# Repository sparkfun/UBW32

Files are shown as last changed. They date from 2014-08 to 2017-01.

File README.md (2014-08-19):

USB 32-Bit Whacker-PIC32MX795 Development Board
================================================

[UBW32
*USB 32-Bit Whacker (DEV-09713)*](https://www.sparkfun.com/products/9713)

This breadboard friendly development board enables you to get the PIC32 up and running quickly. 
Power can be provided over USB, there are 3 push buttons (including 2 user-defined buttons),
and 5 indicator LEDs. The board comes pre-loaded with a USB bootloader and special UBW firmware that accepts
simple serial commands to control the various I/O functions. 

Repository Contents
-------------------
* **/Hardware** - All Eagle design files (.brd, .sch, .STL)

License Information
-------------------
Distributed as-is; no warranty is given.

This product is a collaboration with Brian Schmalz.

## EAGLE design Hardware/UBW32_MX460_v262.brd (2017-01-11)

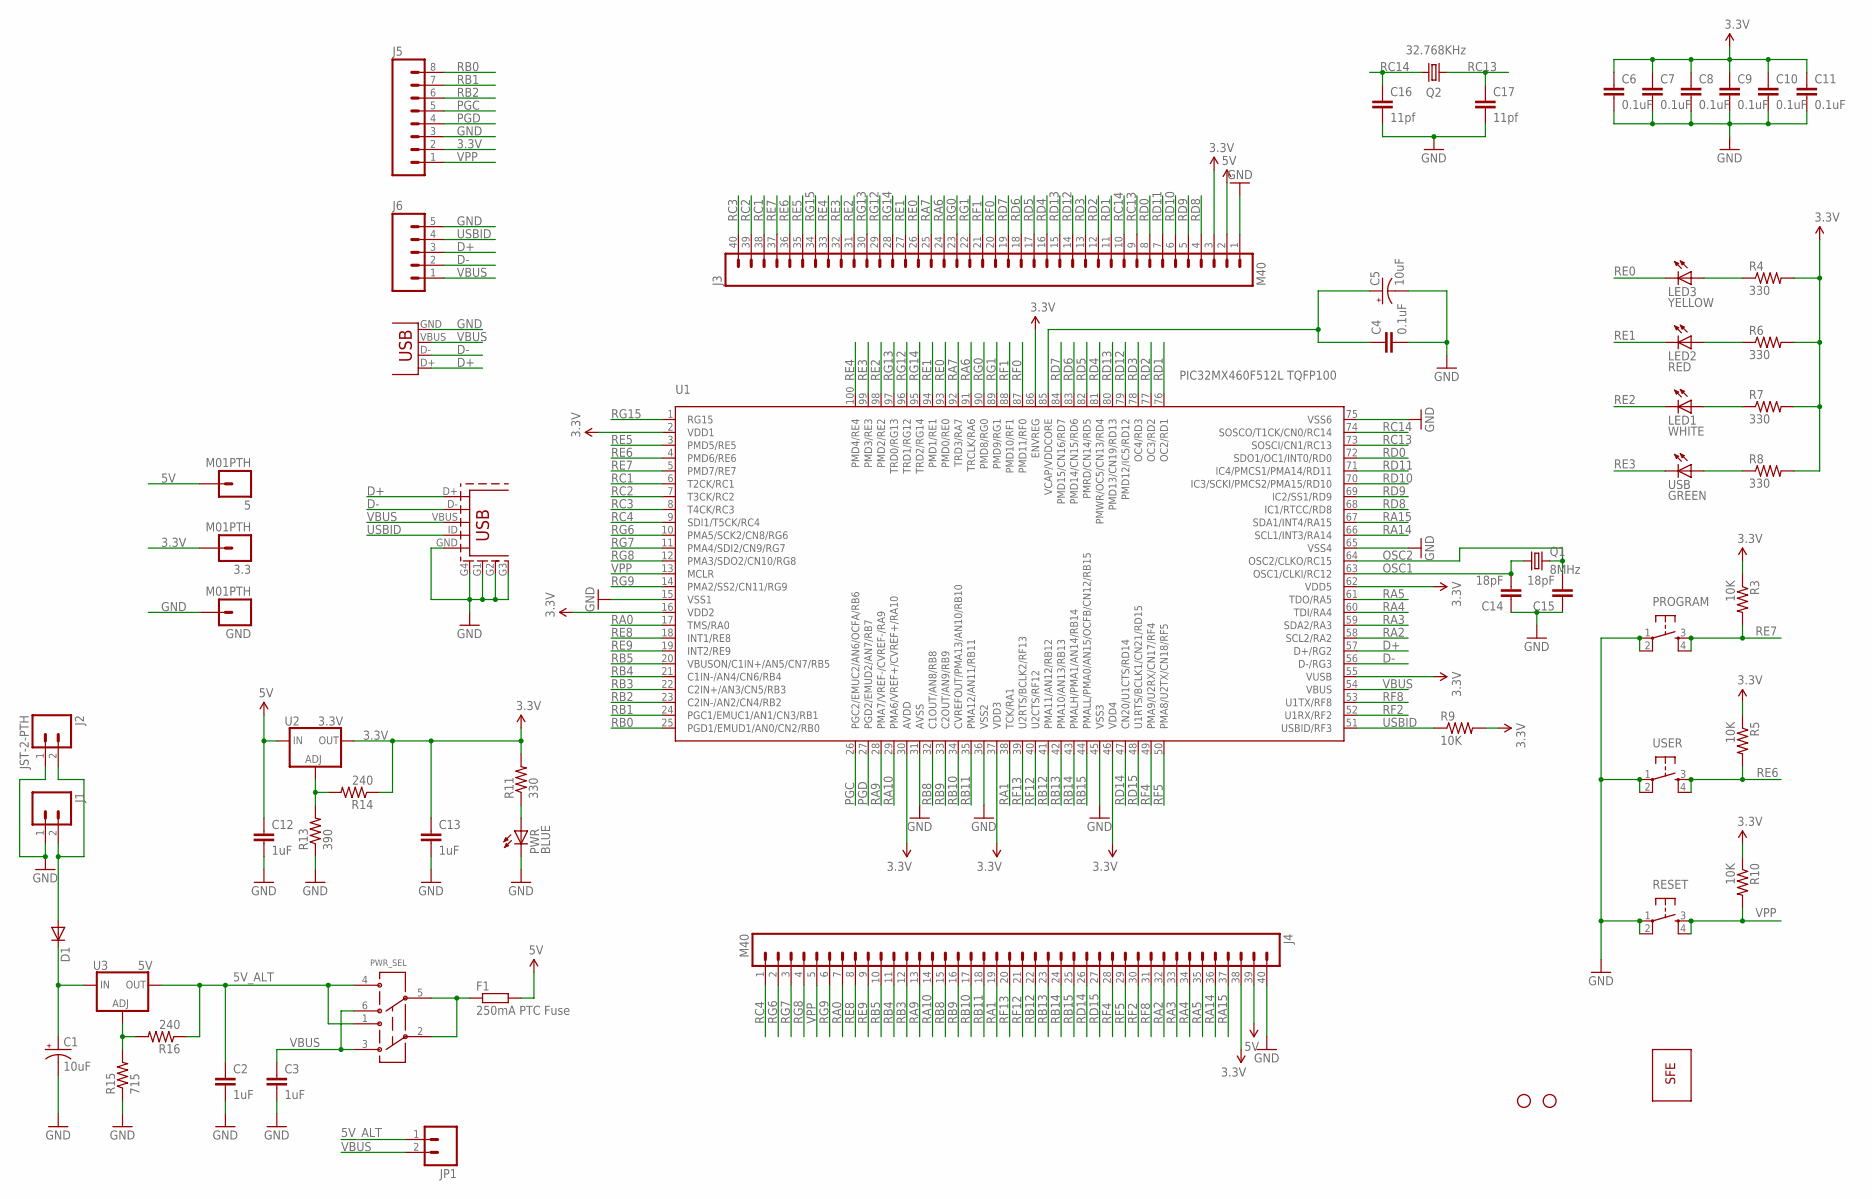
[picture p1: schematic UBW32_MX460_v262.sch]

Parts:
3.3, 5: M01PTH; 1X01
C1, C5: 10uF; EIA3528
C2, C3: 1uF; 0402-CAP
C4, C6, C7, C8, C9, C11: 0.1uF; 0402-CAP
C10: 0.1uF; C0402
C12, C13: 1uF; C0402
C14, C15: 18pF; 0402-CAP
C16, C17: 11pf; 0402-CAP
D1: DIODESMA; SMA-DIODE
F1: 250mA PTC Fuse; R1206
GND: M01PTH; 1X01
J1: M02PTH; 1X02
J2: JST-2-PTH; S2B-PH
J3, J4: M40; 1X40
J5: M08; 1X08
J6: M05PTH; 1X05
J7: USB-A-S
J8: USB-MINIB
JP1: M02PTH; 1X02
LED1: WHITE; LED-0603
LED2: RED; LED-0603
LED3: YELLOW; LED-0603
PROGRAM: TAC_SWITCHSND; TACTILE_SWITCH_SMD
PWR: BLUE; LED-0603
PWR_SEL: AYZ0202
Q1: 8MHz; CRYSTAL-SMD-5X3
Q2: 32.768KHz; CRYSTAL-32KHZ-SMD
R3, R5, R9, R10: 10K; 0402-RES
R4, R6, R7, R8, R11: 330; 0402-RES
R13: 390; 0402-RES
R14, R16: 240; 0402-RES
R15: 715; 0402-RES
RESET: TAC_SWITCHSND; TACTILE_SWITCH_SMD
U1: PIC32MX460F512L TQFP100; TQFP100
U2: 3.3V; SOT223
U3: 5V; SOT223
U$4: LOGO-SFENEW; SFE-NEW-WEBLOGO
U$6, U$7: STAND-OFF
USB: GREEN; LED-0603
USER: TAC_SWITCHSND; TACTILE_SWITCH_SMD

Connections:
3.3V: 3.3.1, C6.1, C7.1, C8.1, C9.1, C10.1, C11.1, C13.1, J3.3, J4.38, J5.2, R3.1, R4.2, R5.1, R6.2, R7.2, R8.2, R9.2, R10.1, R11.2, R14.1, U1.2 (VDD1), U1.16 (VDD2), U1.30 (AVDD), U1.37 (VDD3), U1.46 (VDD4), U1.55 (VUSB), U1.62 (VDD5), U1.86 (ENVREG), U2.2 (OUT)
5V: 5.1, C12.1, F1.2, J3.2, J4.39, U2.3 (IN)
5V_ALT: C2.1, JP1.1, PWR_SEL.1 (3), PWR_SEL.4 (6), R16.1, U3.2 (OUT)
D+: J6.3, J7.D+, J8.D+, U1.57 (D+/RG2)
D-: J6.2, J7.D-, J8.D-, U1.56 (D-/RG3)
GND: C1.C (-), C2.2, C3.2, C4.2, C5.C (-), C6.2, C7.2, C8.2, C9.2, C10.2, C11.2, C12.2, C13.2, C14.1, C15.1, C16.2, C17.2, GND.1, J1.1, J2.1, J3.1, J4.40, J5.3, J6.5, J7.GND, J8.G1, J8.G2, J8.G3, J8.G4 (SHIELD), J8.GND, PROGRAM.1, PROGRAM.2, PWR.C, R13.1, R15.1, RESET.1, RESET.2, U1.15 (VSS1), U1.31 (AVSS), U1.36 (VSS2), U1.45 (VSS3), U1.65 (VSS4), U1.75 (VSS6), USER.1, USER.2
unnamed: D1.A, J1.2, J2.2
unnamed: F1.1, PWR_SEL.2, PWR_SEL.5
unnamed: R13.2, R14.2, U2.1 (ADJ)
unnamed: R15.2, R16.2, U3.1 (ADJ)
unnamed: PWR.A, R11.1
unnamed: R8.1, USB.A
unnamed: LED1.A, R7.1
unnamed: LED2.A, R6.1
unnamed: LED3.A, R4.1
unnamed: C4.1, C5.A (+), U1.85 (VCAP/VDDCORE)
OSC1: C14.2, Q1.1, U1.63 (OSC1/CLKI/RC12)
OSC2: C15.2, Q1.3 (2), U1.64 (OSC2/CLKO/RC15)
PGC: J5.5, U1.26 (PGC2/EMUC2/AN6/OCFA/RB6)
PGD: J5.4, U1.27 (PGD2/EMUD2/AN7/RB7)
RA0: J4.7, U1.17 (TMS/RA0)
RA1: J4.19, U1.38 (TCK/RA1)
RA2: J4.32, U1.58 (SCL2/RA2)
RA3: J4.33, U1.59 (SDA2/RA3)
RA4: J4.34, U1.60 (TDI/RA4)
RA5: J4.35, U1.61 (TDO/RA5)
RA6: J3.24, U1.91 (TRCLK/RA6)
RA7: J3.25, U1.92 (TRD3/RA7)
RA9: J4.13, U1.28 (PMA7/VREF-/CVREF-/RA9)
RA10: J4.14, U1.29 (PMA6/VREF+/CVREF+/RA10)
RA14: J4.36, U1.66 (SCL1/INT3/RA14)
RA15: J4.37, U1.67 (SDA1/INT4/RA15)
RB0: J5.8, U1.25 (PGD1/EMUD1/AN0/CN2/RB0)
RB1: J5.7, U1.24 (PGC1/EMUC1/AN1/CN3/RB1)
RB2: J5.6, U1.23 (C2IN-/AN2/CN4/RB2)
RB3: J4.12, U1.22 (C2IN+/AN3/CN5/RB3)
RB4: J4.11, U1.21 (C1IN-/AN4/CN6/RB4)
RB5: J4.10, U1.20 (VBUSON/C1IN+/AN5/CN7/RB5)
RB8: J4.15, U1.32 (C1OUT/AN8/RB8)
RB9: J4.16, U1.33 (C2OUT/AN9/RB9)
RB10: J4.17, U1.34 (CVREFOUT/PMA13/AN10/RB10)
RB11: J4.18, U1.35 (PMA12/AN11/RB11)
RB12: J4.22, U1.41 (PMA11/AN12/RB12)
RB13: J4.23, U1.42 (PMA10/AN13/RB13)
RB14: J4.24, U1.43 (PMALH/PMA1/AN14/RB14)
RB15: J4.25, U1.44 (PMALL/PMA0/AN15/OCFB/CN12/RB15)
RC1: J3.38, U1.6 (T2CK/RC1)
RC2: J3.39, U1.7 (T3CK/RC2)
RC3: J3.40, U1.8 (T4CK/RC3)
RC4: J4.1, U1.9 (SDI1/T5CK/RC4)
RC13: C17.1, J3.9, Q2.X1 (1), U1.73 (SOSCI/CN1/RC13)
RC14: C16.1, J3.10, Q2.X2 (2), U1.74 (SOSCO/T1CK/CN0/RC14)
RD0: J3.8, U1.72 (SDO1/OC1/INT0/RD0)
RD1: J3.11, U1.76 (OC2/RD1)
RD2: J3.12, U1.77 (OC3/RD2)
RD3: J3.13, U1.78 (OC4/RD3)
RD4: J3.16, U1.81 (PMWR/OC5/CN13/RD4)
RD5: J3.17, U1.82 (PMRD/CN14/RD5)
RD6: J3.18, U1.83 (PMD14/CN15/RD6)
RD7: J3.19, U1.84 (PMD15/CN16/RD7)
RD8: J3.4, U1.68 (IC1/RTCC/RD8)
RD9: J3.5, U1.69 (IC2/SS1/RD9)
RD10: J3.6, U1.70 (IC3/SCKI/PMCS2/PMA15/RD10)
RD11: J3.7, U1.71 (IC4/PMCS1/PMA14/RD11)
RD12: J3.14, U1.79 (PMD12/IC5/RD12)
RD13: J3.15, U1.80 (PMD13/CN19/RD13)
RD14: J4.26, U1.47 (CN20/U1CTS/RD14)
RD15: J4.27, U1.48 (U1RTS/BCLK1/CN21/RD15)
RE0: J3.26, LED3.C, U1.93 (PMD0/RE0)
RE1: J3.27, LED2.C, U1.94 (PMD1/RE1)
RE2: J3.31, LED1.C, U1.98 (PMD2/RE2)
RE3: J3.32, U1.99 (PMD3/RE3), USB.C
RE4: J3.33, U1.100 (PMD4/RE4)
RE5: J3.35, U1.3 (PMD5/RE5)
RE6: J3.36, R5.2, U1.4 (PMD6/RE6), USER.3, USER.4
RE7: J3.37, PROGRAM.3, PROGRAM.4, R3.2, U1.5 (PMD7/RE7)
RE8: J4.8, U1.18 (INT1/RE8)
RE9: J4.9, U1.19 (INT2/RE9)
RF0: J3.20, U1.87 (PMD11/RF0)
RF1: J3.21, U1.88 (PMD10/RF1)
RF2: J4.30, U1.52 (U1RX/RF2)
RF4: J4.28, U1.49 (PMA9/U2RX/CN17/RF4)
RF5: J4.29, U1.50 (PMA8/U2TX/CN18/RF5)
RF8: J4.31, U1.53 (U1TX/RF8)
RF12: J4.21, U1.40 (U2CTS/RF12)
RF13: J4.20, U1.39 (U2RTS/BCLK2/RF13)
RG0: J3.23, U1.90 (PMD8/RG0)
RG1: J3.22, U1.89 (PMD9/RG1)
RG6: J4.2, U1.10 (PMA5/SCK2/CN8/RG6)
RG7: J4.3, U1.11 (PMA4/SDI2/CN9/RG7)
RG8: J4.4, U1.12 (PMA3/SDO2/CN10/RG8)
RG9: J4.6, U1.14 (PMA2/SS2/CN11/RG9)
RG12: J3.29, U1.96 (TRD1/RG12)
RG13: J3.30, U1.97 (TRD0/RG13)
RG14: J3.28, U1.95 (TRD2/RG14)
RG15: J3.34, U1.1 (RG15)
USBID: J6.4, J8.ID (USB_ID), R9.1, U1.51 (USBID/RF3)
VBUS: C3.1, J6.1, J7.VBUS, J8.VBUS, JP1.2, PWR_SEL.3 (1), PWR_SEL.6 (4), U1.54 (VBUS)
VIN_RAW: C1.A (+), D1.C, U3.3 (IN)
VPP: J4.5, J5.1, R10.2, RESET.3, RESET.4, U1.13 (MCLR)

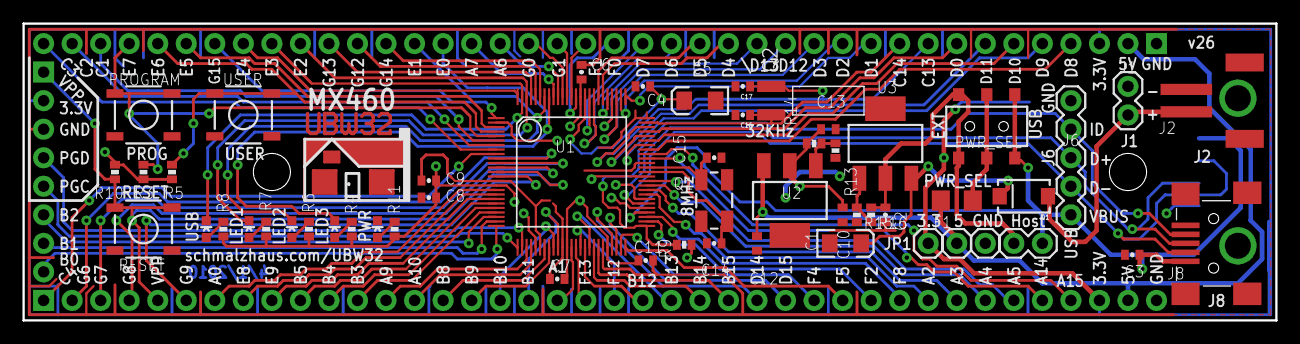
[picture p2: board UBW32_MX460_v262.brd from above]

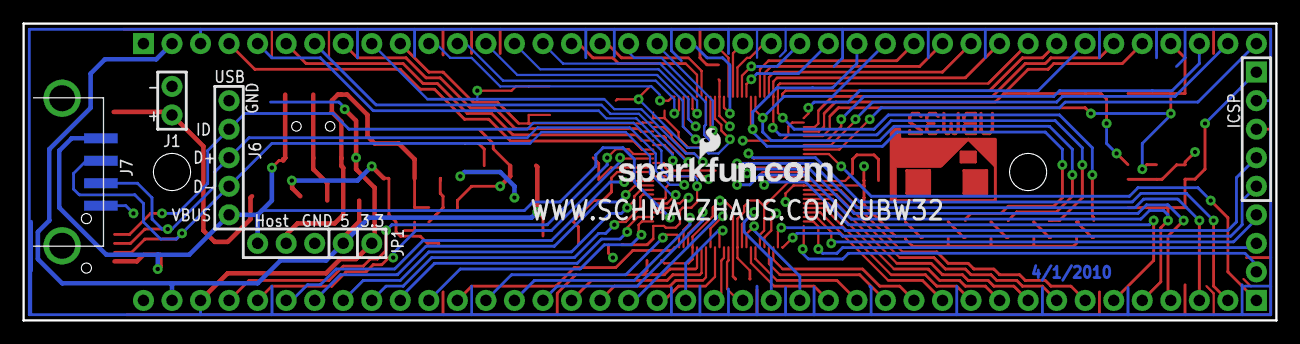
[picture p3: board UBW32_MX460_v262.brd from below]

Board: 2 copper layers, 111.5 x 26.4 mm, 63 parts (2 on the bottom side), 100 nets.

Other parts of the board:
U$3: UBW32
U$5: SCHMALZHAUS

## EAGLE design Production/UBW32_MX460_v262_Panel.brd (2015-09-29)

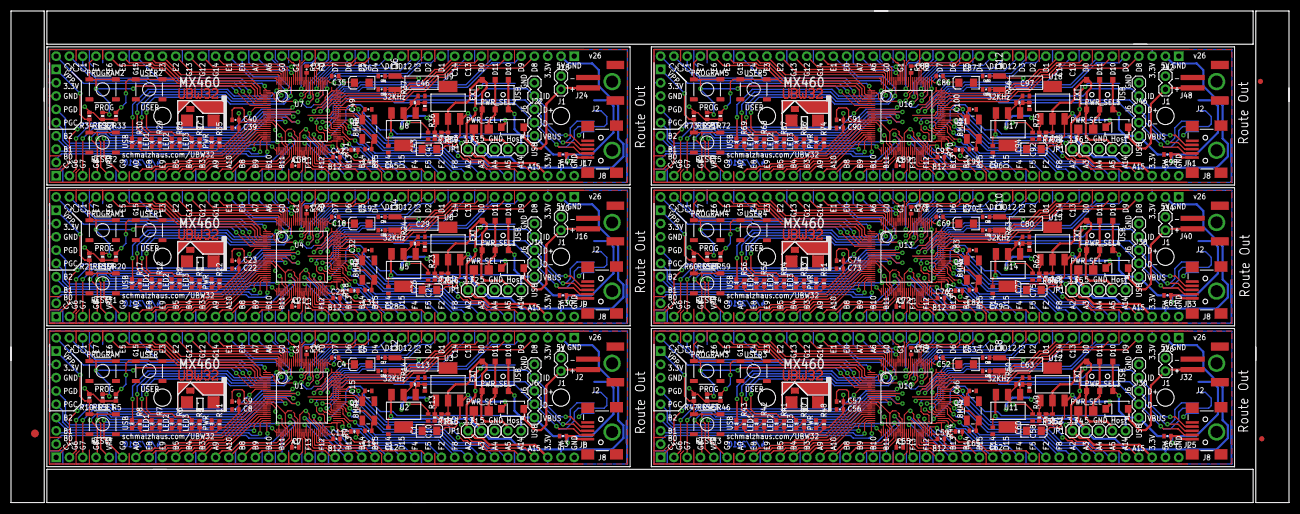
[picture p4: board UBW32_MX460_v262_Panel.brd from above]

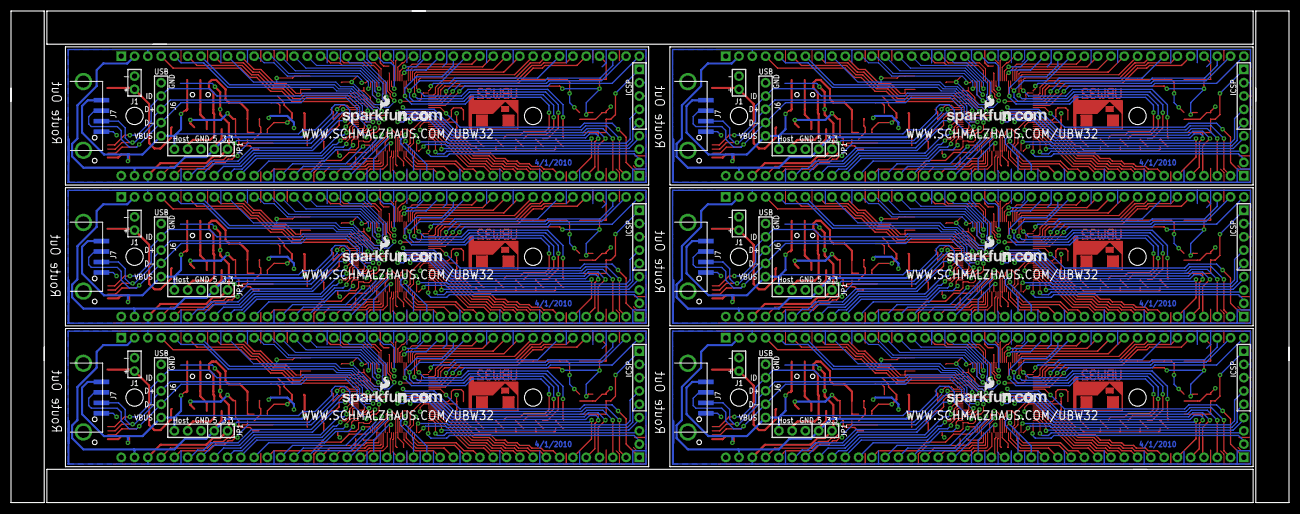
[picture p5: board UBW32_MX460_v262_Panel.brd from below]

Board: 2 copper layers, 244.3 x 94.0 mm, 381 parts (12 on the bottom side), 600 nets.

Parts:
1, 2, 3, 3.1, 3.2, 3.3, 3.4, 3.5, 3.6, 4, 5, 6: M01PTH; 1X01
C1, C5, C19, C26, C36, C43, C53, C60, C70, C77, C87, C94: 10uF; EIA3216
C2, C3, C27, C30, C44, C47, C61, C64, C78, C81, C95, C98: 1uF; 0402-CAP
C4, C6, C7, C8, C9, C11, C18, C20, C21, C22, C23, C25, C35, C37, C38, C39, C40, C42, C52, C54, C55, C56, C57, C59, C69, C71, C72, C73, C74, C76, C86, C88, C89, C90, C91, C93: 0.1uF; 0402-CAP
C10, C24, C41, C58, C75, C92: 0.1uF; C0402
C12, C13, C28, C29, C45, C46, C62, C63, C79, C80, C96, C97: 1uF; C0402
C14, C15, C31, C32, C48, C49, C65, C66, C82, C83, C99, C100: 18pF; 0402-CAP
C16, C17, C33, C34, C50, C51, C67, C68, C84, C85, C101, C102: 11pf; 0402-CAP
D1, D2, D3, D4, D5, D6: SMA-DIODE
E$1: FIDUCIAL-1.5X3
E$5, E$6: FIDUCIAL-1X2
F1, F2, F3, F4, F5, F6: 250mA PTC Fuse; R1206
GND, GND1, GND2, GND3, GND4, GND5: M01PTH; 1X01
J1, J10, J18, J26, J34, J42: 1X02
J2, J16, J24, J32, J40, J48: S2B-PH
J3, J4, J11, J12, J19, J20, J27, J28, J35, J36, J43, J44: M40; 1X40
J5, J13, J21, J29, J37, J45: 1X08
J6, J14, J22, J30, J38, J46: 1X05
J7, J15, J23, J31, J39, J47: USB-A-S
J8, J9, J17, J25, J33, J41: USB-MINIB
JP1, JP2, JP3, JP4, JP5, JP6: 1X02
LED1, LED6, LED9, LED12, LED15, LED18: WHITE; LED-0603
LED2, LED5, LED8, LED11, LED14, LED17: RED; LED-0603
LED3, LED4, LED7, LED10, LED13, LED16: YELLOW; LED-0603
PROGRAM, PROGRAM1, PROGRAM2, PROGRAM3, PROGRAM4, PROGRAM5: TACTILE_SWITCH_SMD
PWR, PWR1, PWR2, PWR3, PWR4, PWR5: BLUE; LED-0603
PWR_SEL, PWR_SEL1, PWR_SEL2, PWR_SEL3, PWR_SEL4, PWR_SEL5: AYZ0202
Q1, Q3, Q5, Q7, Q9, Q11: 8MHz; CRYSTAL-SMD-5X3
Q2, Q4, Q6, Q8, Q10, Q12: 32.768KHz; CRYSTAL-32KHZ-SMD
R1, R2, R4, R6, R7, R8, R11, R12, R17, R22, R27, R28, R29, R30, R35, R40, R41, R42, R43, R48, R53, R54, R55, R56, R61, R66, R67, R68, R69, R74: 330; 0402-RES
R3, R5, R9, R10, R18, R19, R20, R21, R31, R32, R33, R34, R44, R45, R46, R47, R57, R58, R59, R60, R70, R71, R72, R73: 10K; 0402-RES
R13, R23, R36, R49, R62, R75: 390; 0402-RES
R14, R16, R24, R26, R37, R39, R50, R52, R63, R65, R76, R78: 240; 0402-RES
R15, R25, R38, R51, R64, R77: 715; 0402-RES
RESET, RESET1, RESET2, RESET3, RESET4, RESET5: TACTILE_SWITCH_SMD
U1, U4, U7, U10, U13, U16: PIC32MX460F512L TQFP100; TQFP100
U2, U5, U8, U11, U14, U17: 3.3V; SOT223
U3, U6, U9, U12, U15, U18: 5V; SOT223
U$1, U$2, U$6, U$7, U$11, U$12, U$16, U$17, U$21, U$22, U$26, U$27: STAND-OFF
U$3, U$9, U$14, U$19, U$24, U$29: UBW32
U$4, U$8, U$13, U$18, U$23, U$28: LOGO-SFENEW; SFE-NEW-WEBLOGO
U$5, U$10, U$15, U$20, U$25, U$30: SCHMALZHAUS
USB, USB1, USB2, USB3, USB4, USB5: GREEN; LED-0603
USER, USER1, USER2, USER3, USER4, USER5: TACTILE_SWITCH_SMD

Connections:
3.3V: 3.3.1, C6.1, C7.1, C8.1, C9.1, C10.1, C11.1, C13.1, J3.3, J4.38, J5.2, R3.1, R4.2, R5.1, R6.2, R7.2, R8.2, R9.2, R10.1, R11.2, R14.1, U1.2, U1.16, U1.30, U1.37, U1.46, U1.55, U1.62, U1.86, U2.2
3.3V1: 3.1.1, C20.1, C21.1, C22.1, C23.1, C24.1, C25.1, C29.1, J11.3, J12.38, J13.2, R1.2, R2.2, R12.2, R17.2, R18.2, R19.1, R20.1, R21.1, R22.2, R24.1, U4.2, U4.16, U4.30, U4.37, U4.46, U4.55, U4.62, U4.86, U5.2
3.3V2: 3.2.1, C37.1, C38.1, C39.1, C40.1, C41.1, C42.1, C46.1, J19.3, J20.38, J21.2, R27.2, R28.2, R29.2, R30.2, R31.2, R32.1, R33.1, R34.1, R35.2, R37.1, U7.2, U7.16, U7.30, U7.37, U7.46, U7.55, U7.62, U7.86, U8.2
3.3V3: 3.4.1, C54.1, C55.1, C56.1, C57.1, C58.1, C59.1, C63.1, J27.3, J28.38, J29.2, R40.2, R41.2, R42.2, R43.2, R44.2, R45.1, R46.1, R47.1, R48.2, R50.1, U10.2, U10.16, U10.30, U10.37, U10.46, U10.55, U10.62, U10.86, U11.2
3.3V4: 3.5.1, C71.1, C72.1, C73.1, C74.1, C75.1, C76.1, C80.1, J35.3, J36.38, J37.2, R53.2, R54.2, R55.2, R56.2, R57.2, R58.1, R59.1, R60.1, R61.2, R63.1, U13.2, U13.16, U13.30, U13.37, U13.46, U13.55, U13.62, U13.86, U14.2
3.3V5: 3.6.1, C88.1, C89.1, C90.1, C91.1, C92.1, C93.1, C97.1, J43.3, J44.38, J45.2, R66.2, R67.2, R68.2, R69.2, R70.2, R71.1, R72.1, R73.1, R74.2, R76.1, U16.2, U16.16, U16.30, U16.37, U16.46, U16.55, U16.62, U16.86, U17.2
5V: 5.1, C12.1, F1.2, J3.2, J4.39, U2.3
5V1: 1.1, C28.1, F2.2, J11.2, J12.39, U5.3
5V2: 2.1, C45.1, F3.2, J19.2, J20.39, U8.3
5V3: 3.1, C62.1, F4.2, J27.2, J28.39, U11.3
5V4: 4.1, C79.1, F5.2, J35.2, J36.39, U14.3
5V5: 6.1, C96.1, F6.2, J43.2, J44.39, U17.3
5V_ALT: C2.1, JP1.1, PWR_SEL.1, PWR_SEL.4, R16.1, U3.2
5V_ALT1: C27.1, JP2.1, PWR_SEL1.1, PWR_SEL1.4, R26.1, U6.2
5V_ALT2: C44.1, JP3.1, PWR_SEL2.1, PWR_SEL2.4, R39.1, U9.2
5V_ALT3: C61.1, JP4.1, PWR_SEL3.1, PWR_SEL3.4, R52.1, U12.2
5V_ALT4: C78.1, JP5.1, PWR_SEL4.1, PWR_SEL4.4, R65.1, U15.2
5V_ALT5: C95.1, JP6.1, PWR_SEL5.1, PWR_SEL5.4, R78.1, U18.2
D+: J6.3, J7.D+, J8.D+, U1.57
D+1: J9.D+, J14.3, J15.D+, U4.57
D+2: J17.D+, J22.3, J23.D+, U7.57
D+3: J25.D+, J30.3, J31.D+, U10.57
D+4: J33.D+, J38.3, J39.D+, U13.57
D+5: J41.D+, J46.3, J47.D+, U16.57
D-: J6.2, J7.D-, J8.D-, U1.56
D-1: J9.D-, J14.2, J15.D-, U4.56
D-2: J17.D-, J22.2, J23.D-, U7.56
D-3: J25.D-, J30.2, J31.D-, U10.56
D-4: J33.D-, J38.2, J39.D-, U13.56
D-5: J41.D-, J46.2, J47.D-, U16.56
GND: C1.C, C2.2, C3.2, C4.2, C5.C, C6.2, C7.2, C8.2, C9.2, C10.2, C11.2, C12.2, C13.2, C14.1, C15.1, C16.2, C17.2, GND.1, J1.1, J2.1, J3.1, J4.40, J5.3, J6.5, J7.GND, J8.G1, J8.G2, J8.G3, J8.G4, J8.GND, PROGRAM.1, PROGRAM.2, PWR.C, R13.1, R15.1, RESET.1, RESET.2, U1.15, U1.31, U1.36, U1.45, U1.65, U1.75, USER.1, USER.2
GND1: C18.2, C19.C, C20.2, C21.2, C22.2, C23.2, C24.2, C25.2, C26.C, C27.2, C28.2, C29.2, C30.2, C31.1, C32.1, C33.2, C34.2, GND1.1, J9.G1, J9.G2, J9.G3, J9.G4, J9.GND, J10.1, J11.1, J12.40, J13.3, J14.5, J15.GND, J16.1, PROGRAM1.1, PROGRAM1.2, PWR1.C, R23.1, R25.1, RESET1.1, RESET1.2, U4.15, U4.31, U4.36, U4.45, U4.65, U4.75, USER1.1, USER1.2
GND2: C35.2, C36.C, C37.2, C38.2, C39.2, C40.2, C41.2, C42.2, C43.C, C44.2, C45.2, C46.2, C47.2, C48.1, C49.1, C50.2, C51.2, GND2.1, J17.G1, J17.G2, J17.G3, J17.G4, J17.GND, J18.1, J19.1, J20.40, J21.3, J22.5, J23.GND, J24.1, PROGRAM2.1, PROGRAM2.2, PWR2.C, R36.1, R38.1, RESET2.1, RESET2.2, U7.15, U7.31, U7.36, U7.45, U7.65, U7.75, USER2.1, USER2.2
GND3: C52.2, C53.C, C54.2, C55.2, C56.2, C57.2, C58.2, C59.2, C60.C, C61.2, C62.2, C63.2, C64.2, C65.1, C66.1, C67.2, C68.2, GND3.1, J25.G1, J25.G2, J25.G3, J25.G4, J25.GND, J26.1, J27.1, J28.40, J29.3, J30.5, J31.GND, J32.1, PROGRAM3.1, PROGRAM3.2, PWR3.C, R49.1, R51.1, RESET3.1, RESET3.2, U10.15, U10.31, U10.36, U10.45, U10.65, U10.75, USER3.1, USER3.2
GND4: C69.2, C70.C, C71.2, C72.2, C73.2, C74.2, C75.2, C76.2, C77.C, C78.2, C79.2, C80.2, C81.2, C82.1, C83.1, C84.2, C85.2, GND4.1, J33.G1, J33.G2, J33.G3, J33.G4, J33.GND, J34.1, J35.1, J36.40, J37.3, J38.5, J39.GND, J40.1, PROGRAM4.1, PROGRAM4.2, PWR4.C, R62.1, R64.1, RESET4.1, RESET4.2, U13.15, U13.31, U13.36, U13.45, U13.65, U13.75, USER4.1, USER4.2
GND5: C86.2, C87.C, C88.2, C89.2, C90.2, C91.2, C92.2, C93.2, C94.C, C95.2, C96.2, C97.2, C98.2, C99.1, C100.1, C101.2, C102.2, GND5.1, J41.G1, J41.G2, J41.G3, J41.G4, J41.GND, J42.1, J43.1, J44.40, J45.3, J46.5, J47.GND, J48.1, PROGRAM5.1, PROGRAM5.2, PWR5.C, R75.1, R77.1, RESET5.1, RESET5.2, U16.15, U16.31, U16.36, U16.45, U16.65, U16.75, USER5.1, USER5.2
unnamed: D1.A, J1.2, J2.2
unnamed: F1.1, PWR_SEL.2, PWR_SEL.5
unnamed: R13.2, R14.2, U2.1
unnamed: R15.2, R16.2, U3.1
unnamed: C18.1, C19.A, U4.85
unnamed: PWR.A, R11.1
unnamed: R17.1, USB1.A
unnamed: LED6.A, R12.1
unnamed: LED5.A, R2.1
unnamed: LED4.A, R1.1
unnamed: PWR1.A, R22.1
unnamed: D2.A, J10.2, J16.2
unnamed: F2.1, PWR_SEL1.2, PWR_SEL1.5
unnamed: R23.2, R24.2, U5.1
unnamed: R25.2, R26.2, U6.1
unnamed: C35.1, C36.A, U7.85
unnamed: R30.1, USB2.A
unnamed: LED9.A, R29.1
unnamed: LED8.A, R28.1
unnamed: R8.1, USB.A
unnamed: LED7.A, R27.1
unnamed: LED1.A, R7.1
unnamed: LED2.A, R6.1
unnamed: PWR2.A, R35.1
unnamed: D3.A, J18.2, J24.2
unnamed: F3.1, PWR_SEL2.2, PWR_SEL2.5
unnamed: R36.2, R37.2, U8.1
unnamed: R38.2, R39.2, U9.1
unnamed: C52.1, C53.A, U10.85
unnamed: R43.1, USB3.A
unnamed: LED12.A, R42.1
unnamed: LED11.A, R41.1
unnamed: LED10.A, R40.1
unnamed: PWR3.A, R48.1
unnamed: LED3.A, R4.1
unnamed: D4.A, J26.2, J32.2
unnamed: F4.1, PWR_SEL3.2, PWR_SEL3.5
unnamed: R49.2, R50.2, U11.1
unnamed: R51.2, R52.2, U12.1
unnamed: C69.1, C70.A, U13.85
unnamed: R56.1, USB4.A
unnamed: LED15.A, R55.1
unnamed: LED14.A, R54.1
unnamed: LED13.A, R53.1
unnamed: PWR4.A, R61.1
unnamed: D5.A, J34.2, J40.2
unnamed: F5.1, PWR_SEL4.2, PWR_SEL4.5
unnamed: R62.2, R63.2, U14.1
unnamed: R64.2, R65.2, U15.1
unnamed: C86.1, C87.A, U16.85
unnamed: R69.1, USB5.A
unnamed: LED18.A, R68.1
unnamed: LED17.A, R67.1
unnamed: LED16.A, R66.1
unnamed: PWR5.A, R74.1
unnamed: D6.A, J42.2, J48.2
unnamed: F6.1, PWR_SEL5.2, PWR_SEL5.5
unnamed: R75.2, R76.2, U17.1
unnamed: R77.2, R78.2, U18.1
unnamed: C4.1, C5.A, U1.85
OSC1: C14.2, Q1.1, U1.63
OSC2: C15.2, Q1.3, U1.64
OSC3: C32.2, Q3.3, U4.64
OSC4: C31.2, Q3.1, U4.63
OSC5: C49.2, Q5.3, U7.64
OSC6: C48.2, Q5.1, U7.63
OSC7: C66.2, Q7.3, U10.64
OSC8: C65.2, Q7.1, U10.63
OSC9: C83.2, Q9.3, U13.64
OSC10: C82.2, Q9.1, U13.63
OSC11: C100.2, Q11.3, U16.64
OSC12: C99.2, Q11.1, U16.63
PGC: J5.5, U1.26
PGC1: J13.5, U4.26
PGC2: J21.5, U7.26
PGC3: J29.5, U10.26
PGC4: J37.5, U13.26
PGC5: J45.5, U16.26
PGD: J5.4, U1.27
PGD1: J13.4, U4.27
PGD2: J21.4, U7.27
PGD3: J29.4, U10.27
PGD4: J37.4, U13.27
PGD5: J45.4, U16.27
RA0: J4.7, U1.17
RA1: J4.19, U1.38
RA2: J4.32, U1.58
RA3: J4.33, U1.59
RA4: J4.34, U1.60
RA5: J4.35, U1.61
RA6: J3.24, U1.91
RA7: J3.25, U1.92
RA8: J12.32, U4.58
RA9: J4.13, U1.28
RA10: J4.14, U1.29
RA11: J12.33, U4.59
RA12: J11.24, U4.91
RA13: J11.25, U4.92
RA14: J4.36, U1.66
RA15: J4.37, U1.67
RA16: J12.34, U4.60
RA17: J12.35, U4.61
RA18: J12.7, U4.17
RA19: J12.13, U4.28
RA20: J12.14, U4.29
RA21: J12.19, U4.38
RA22: J12.36, U4.66
RA23: J12.37, U4.67
RA24: J20.32, U7.58
RA25: J20.33, U7.59
RA26: J19.24, U7.91
RA27: J19.25, U7.92
RA28: J20.34, U7.60
RA29: J20.35, U7.61
RA30: J20.7, U7.17
RA31: J20.13, U7.28
RA32: J20.14, U7.29
RA33: J20.19, U7.38
RA34: J20.36, U7.66
RA35: J20.37, U7.67
RA36: J28.32, U10.58
RA37: J28.33, U10.59
RA38: J27.24, U10.91
RA39: J27.25, U10.92
RA40: J28.34, U10.60
RA41: J28.35, U10.61
RA42: J28.7, U10.17
RA43: J28.13, U10.28
RA44: J28.14, U10.29
RA45: J28.19, U10.38
RA46: J28.36, U10.66
RA47: J28.37, U10.67
RA48: J36.32, U13.58
RA49: J36.33, U13.59
RA50: J35.24, U13.91
RA51: J35.25, U13.92
RA52: J36.34, U13.60
RA53: J36.35, U13.61
RA54: J36.7, U13.17
RA55: J36.13, U13.28
RA56: J36.14, U13.29
RA57: J36.19, U13.38
RA58: J36.36, U13.66
RA59: J36.37, U13.67
RA60: J44.32, U16.58
RA61: J44.33, U16.59
RA62: J43.24, U16.91
RA63: J43.25, U16.92
RA64: J44.34, U16.60
RA65: J44.35, U16.61
RA66: J44.7, U16.17
RA67: J44.13, U16.28
RA68: J44.14, U16.29
RA69: J44.19, U16.38
RA70: J44.36, U16.66
RA71: J44.37, U16.67
RB0: J5.8, U1.25
RB1: J5.7, U1.24
RB2: J5.6, U1.23
RB3: J4.12, U1.22
RB4: J4.11, U1.21
RB5: J4.10, U1.20
RB6: J13.8, U4.25
RB7: J13.7, U4.24
RB8: J4.15, U1.32
RB9: J4.16, U1.33
RB10: J4.17, U1.34
RB11: J4.18, U1.35
RB12: J4.22, U1.41
RB13: J4.23, U1.42
RB14: J4.24, U1.43
RB15: J4.25, U1.44
RB16: J12.10, U4.20
RB17: J12.11, U4.21
RB18: J12.12, U4.22
RB19: J13.6, U4.23
RB20: J12.15, U4.32
RB21: J12.16, U4.33
RB22: J12.17, U4.34
RB23: J12.18, U4.35
RB24: J12.22, U4.41
RB25: J12.23, U4.42
RB26: J12.24, U4.43
RB27: J12.25, U4.44
RB28: J21.8, U7.25
RB29: J21.7, U7.24
RB30: J20.10, U7.20
RB31: J20.11, U7.21
RB32: J20.12, U7.22
RB33: J21.6, U7.23
RB34: J20.15, U7.32
RB35: J20.16, U7.33
RB36: J20.17, U7.34
RB37: J20.18, U7.35
RB38: J20.22, U7.41
RB39: J20.23, U7.42
RB40: J20.24, U7.43
RB41: J20.25, U7.44
RB42: J29.8, U10.25
RB43: J29.7, U10.24
RB44: J28.10, U10.20
RB45: J28.11, U10.21
RB46: J28.12, U10.22
RB47: J29.6, U10.23
RB48: J28.15, U10.32
RB49: J28.16, U10.33
RB50: J28.17, U10.34
RB51: J28.18, U10.35
RB52: J28.22, U10.41
RB53: J28.23, U10.42
RB54: J28.24, U10.43
RB55: J28.25, U10.44
RB56: J37.8, U13.25
RB57: J37.7, U13.24
RB58: J36.10, U13.20
RB59: J36.11, U13.21
RB60: J36.12, U13.22
RB61: J37.6, U13.23
RB62: J36.15, U13.32
RB63: J36.16, U13.33
RB64: J36.17, U13.34
RB65: J36.18, U13.35
RB66: J36.22, U13.41
RB67: J36.23, U13.42
RB68: J36.24, U13.43
RB69: J36.25, U13.44
RB70: J45.8, U16.25
RB71: J45.7, U16.24
RB72: J44.10, U16.20
RB73: J44.11, U16.21
RB74: J44.12, U16.22
RB75: J45.6, U16.23
RB76: J44.15, U16.32
RB77: J44.16, U16.33
RB78: J44.17, U16.34
RB79: J44.18, U16.35
RB80: J44.22, U16.41
RB81: J44.23, U16.42
RB82: J44.24, U16.43
RB83: J44.25, U16.44
RC1: J3.38, U1.6
RC2: J3.39, U1.7
RC3: J3.40, U1.8
RC4: J4.1, U1.9
RC5: J11.38, U4.6
RC6: J11.39, U4.7
RC7: J11.40, U4.8
RC8: J12.1, U4.9
RC9: C34.1, J11.9, Q4.X1, U4.73
RC10: C33.1, J11.10, Q4.X2, U4.74
RC11: J19.38, U7.6
RC12: J19.39, U7.7
RC13: C17.1, J3.9, Q2.X1, U1.73
RC14: C16.1, J3.10, Q2.X2, U1.74
RC15: J19.40, U7.8
RC16: J20.1, U7.9
RC17: C51.1, J19.9, Q6.X1, U7.73
RC18: C50.1, J19.10, Q6.X2, U7.74
RC19: J27.38, U10.6
RC20: J27.39, U10.7
RC21: J27.40, U10.8
RC22: J28.1, U10.9
RC23: C68.1, J27.9, Q8.X1, U10.73
RC24: C67.1, J27.10, Q8.X2, U10.74
RC25: J35.38, U13.6
RC26: J35.39, U13.7
RC27: J35.40, U13.8
RC28: J36.1, U13.9
RC29: C85.1, J35.9, Q10.X1, U13.73
RC30: C84.1, J35.10, Q10.X2, U13.74
RC31: J43.38, U16.6
RC32: J43.39, U16.7
RC33: J43.40, U16.8
RC34: J44.1, U16.9
RC35: C102.1, J43.9, Q12.X1, U16.73
RC36: C101.1, J43.10, Q12.X2, U16.74
RD0: J3.8, U1.72
RD1: J3.11, U1.76
RD2: J3.12, U1.77
RD3: J3.13, U1.78
RD4: J3.16, U1.81
RD5: J3.17, U1.82
RD6: J3.18, U1.83
RD7: J3.19, U1.84
RD8: J3.4, U1.68
RD9: J3.5, U1.69
RD10: J3.6, U1.70
RD11: J3.7, U1.71
RD12: J3.14, U1.79
RD13: J3.15, U1.80
RD14: J4.26, U1.47
RD15: J4.27, U1.48
RD16: J12.26, U4.47
RD17: J12.27, U4.48
RD18: J11.4, U4.68
RD19: J11.5, U4.69
RD20: J11.6, U4.70
RD21: J11.7, U4.71
RD22: J11.8, U4.72
RD23: J11.11, U4.76
RD24: J11.12, U4.77
RD25: J11.13, U4.78
RD26: J11.14, U4.79
RD27: J11.15, U4.80
RD28: J11.16, U4.81
RD29: J11.17, U4.82
RD30: J11.18, U4.83
RD31: J11.19, U4.84
RD32: J20.26, U7.47
RD33: J20.27, U7.48
RD34: J19.4, U7.68
RD35: J19.5, U7.69
RD36: J19.6, U7.70
RD37: J19.7, U7.71
RD38: J19.8, U7.72
RD39: J19.11, U7.76
RD40: J19.12, U7.77
RD41: J19.13, U7.78
RD42: J19.14, U7.79
RD43: J19.15, U7.80
RD44: J19.16, U7.81
RD45: J19.17, U7.82
RD46: J19.18, U7.83
RD47: J19.19, U7.84
RD48: J28.26, U10.47
RD49: J28.27, U10.48
RD50: J27.4, U10.68
RD51: J27.5, U10.69
RD52: J27.6, U10.70
RD53: J27.7, U10.71
RD54: J27.8, U10.72
RD55: J27.11, U10.76
RD56: J27.12, U10.77
RD57: J27.13, U10.78
RD58: J27.14, U10.79
RD59: J27.15, U10.80
RD60: J27.16, U10.81
RD61: J27.17, U10.82
RD62: J27.18, U10.83
RD63: J27.19, U10.84
RD64: J36.26, U13.47
RD65: J36.27, U13.48
RD66: J35.4, U13.68
RD67: J35.5, U13.69
RD68: J35.6, U13.70
RD69: J35.7, U13.71
RD70: J35.8, U13.72
RD71: J35.11, U13.76
RD72: J35.12, U13.77
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

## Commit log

2014-08-19 Adding hardware files and README info
    [UBW32_MX460_v262.brd, UBW32_MX460_v262.sch]
2015-09-29 new larger panel
    [UBW32_MX460_v262_Panel.brd]
2017-01-10 .brd file Values Updated
    [UBW32_MX460_v262.sch]
2017-01-11 .brd Values Added
    [UBW32_MX460_v262.brd]

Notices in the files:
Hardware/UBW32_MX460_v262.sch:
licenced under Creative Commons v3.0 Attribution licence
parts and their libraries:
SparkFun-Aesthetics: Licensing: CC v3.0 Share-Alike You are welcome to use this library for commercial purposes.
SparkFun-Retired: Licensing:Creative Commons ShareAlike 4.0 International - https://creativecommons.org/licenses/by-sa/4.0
